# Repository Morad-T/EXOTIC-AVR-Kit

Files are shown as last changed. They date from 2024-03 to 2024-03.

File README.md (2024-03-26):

# AVR Kit

AVR Dev. Kit based on the ATMEGA32A
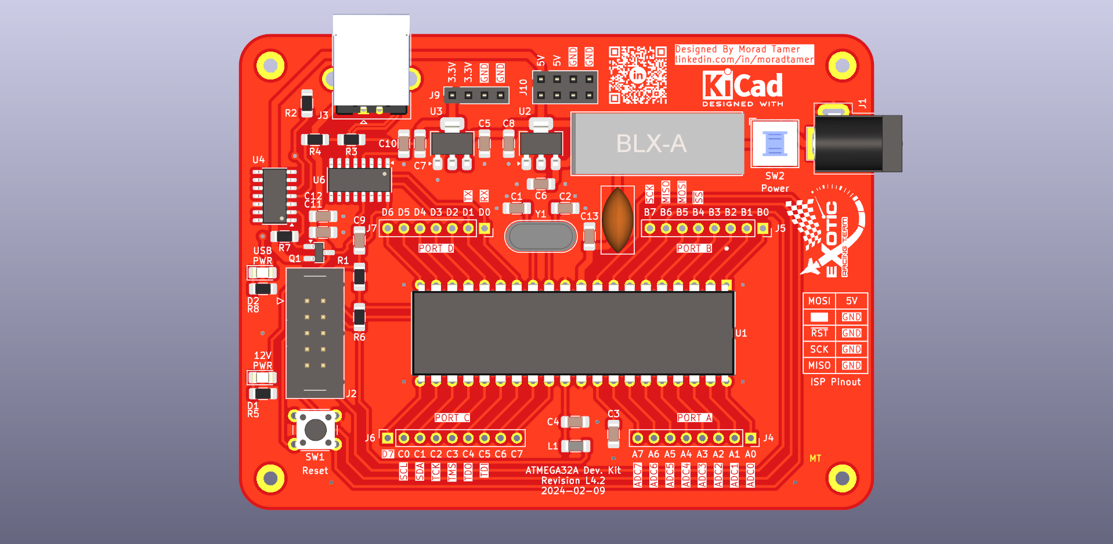
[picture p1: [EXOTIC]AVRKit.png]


## Features

- Only 2 Layer PCB
- Can accomodate ZIF or normal 40-Pin sockets
- Over Current Protection
- CH340C USB to UART Interface
- Direct 10-Pin ISP Interface

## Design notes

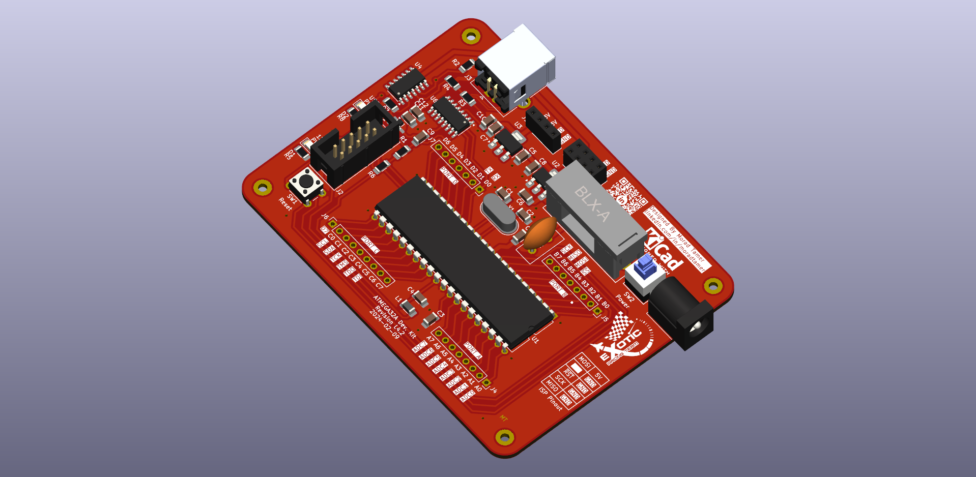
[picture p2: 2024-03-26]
[EXOTIC]AVRKitIsometric.png

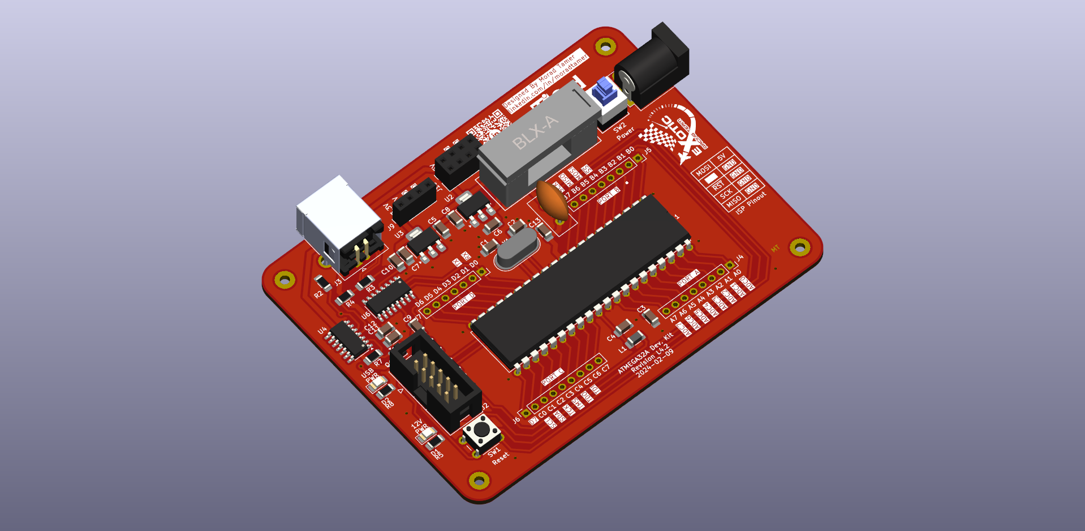
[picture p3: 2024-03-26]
[EXOTIC]AVRKitIsometric2.png

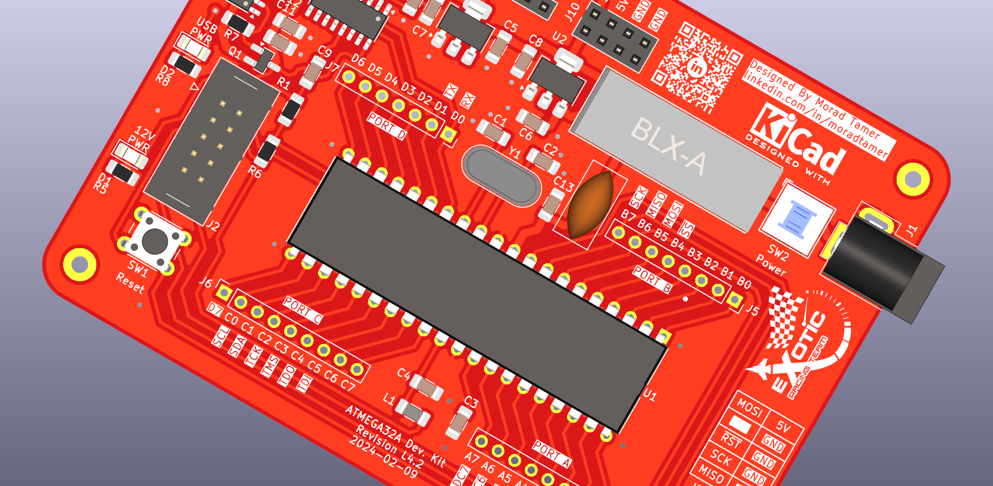
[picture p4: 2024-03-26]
[EXOTIC]AVRKitCover.png

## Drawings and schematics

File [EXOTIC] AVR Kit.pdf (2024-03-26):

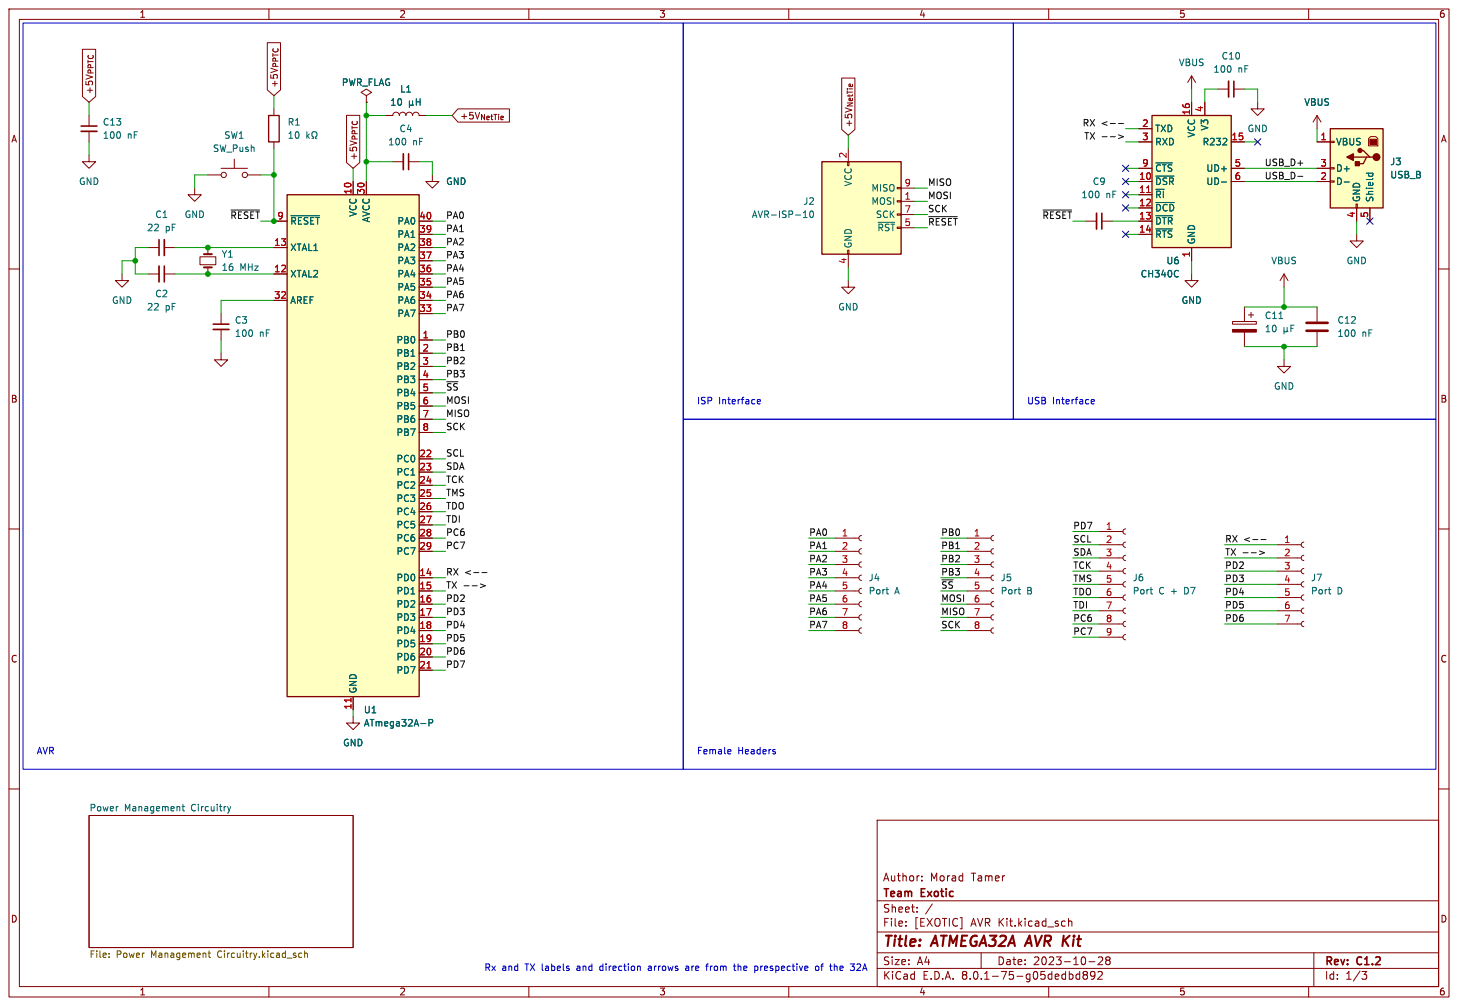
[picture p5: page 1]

VBUS GND +5V_{NetTie} +5V_{PPTC} +5V_{PPTC}

4 UD+ 5 UD- 6 ~{CTS} 9 U6 CH340C GND

1 ~{DSR} 10 ~{RI} 11 ~{DCD} 12 ~{DTR} 13 ~{RTS} 14 R232 VCC 15 16 TXD 2 RXD 3 V3

4 UD+ 5 UD- 6 ~{CTS} 9 GND

SCL PD5 PD3 PD6 PD2 TX --> MOSI MISO

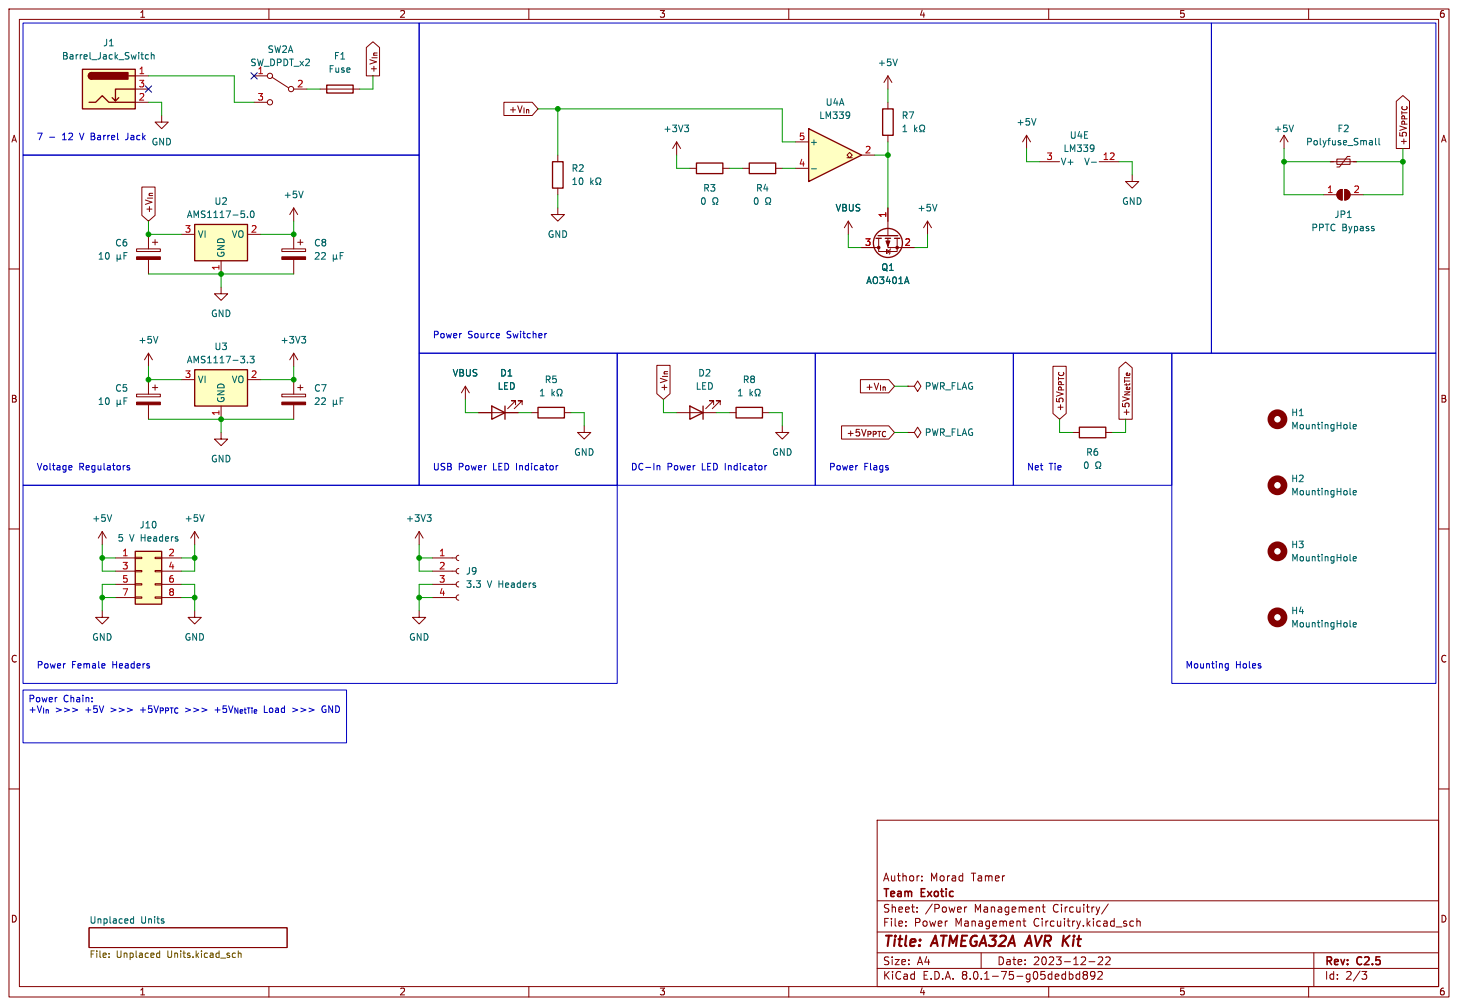
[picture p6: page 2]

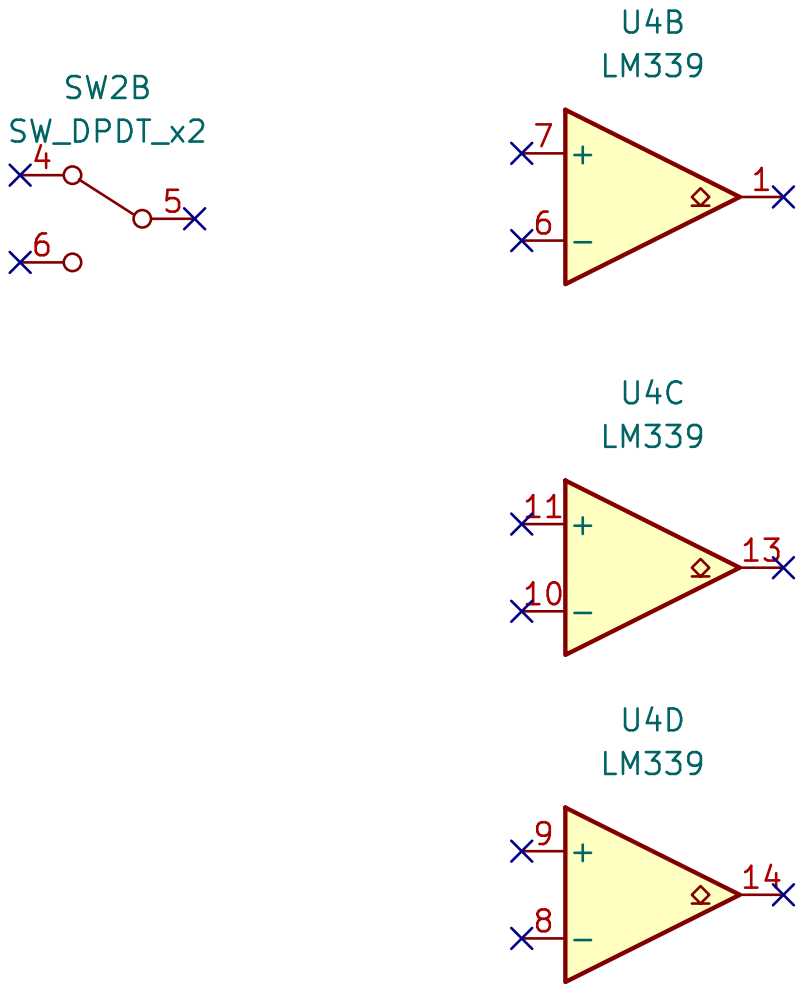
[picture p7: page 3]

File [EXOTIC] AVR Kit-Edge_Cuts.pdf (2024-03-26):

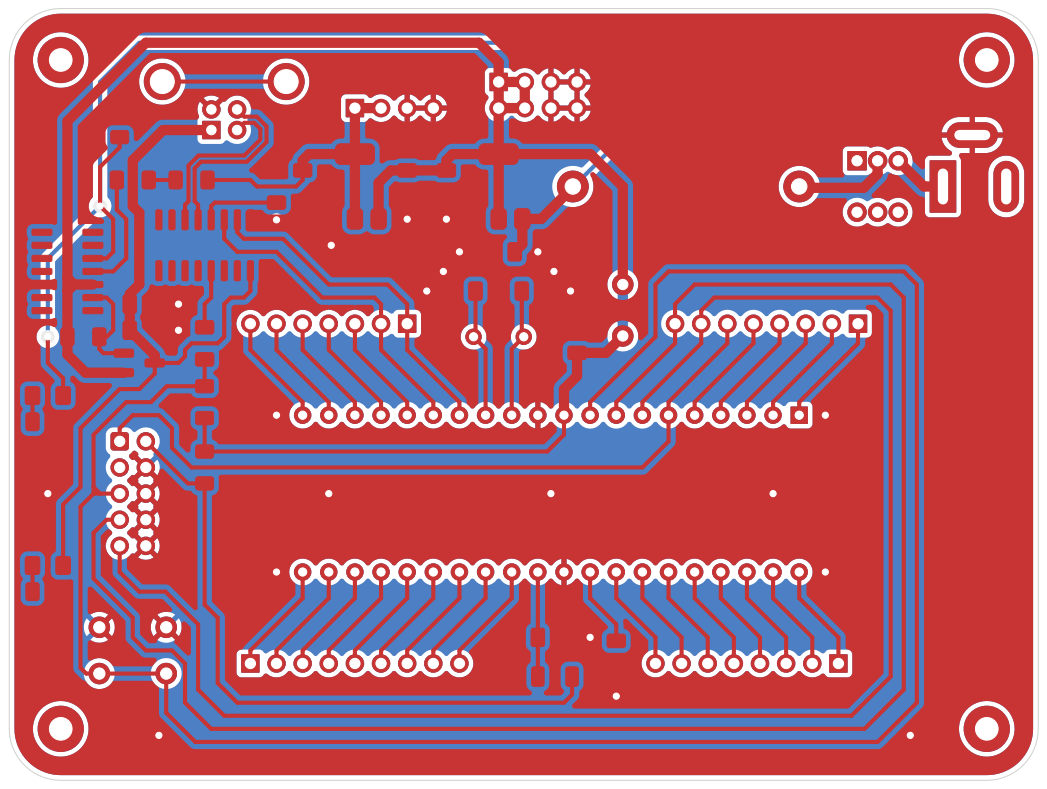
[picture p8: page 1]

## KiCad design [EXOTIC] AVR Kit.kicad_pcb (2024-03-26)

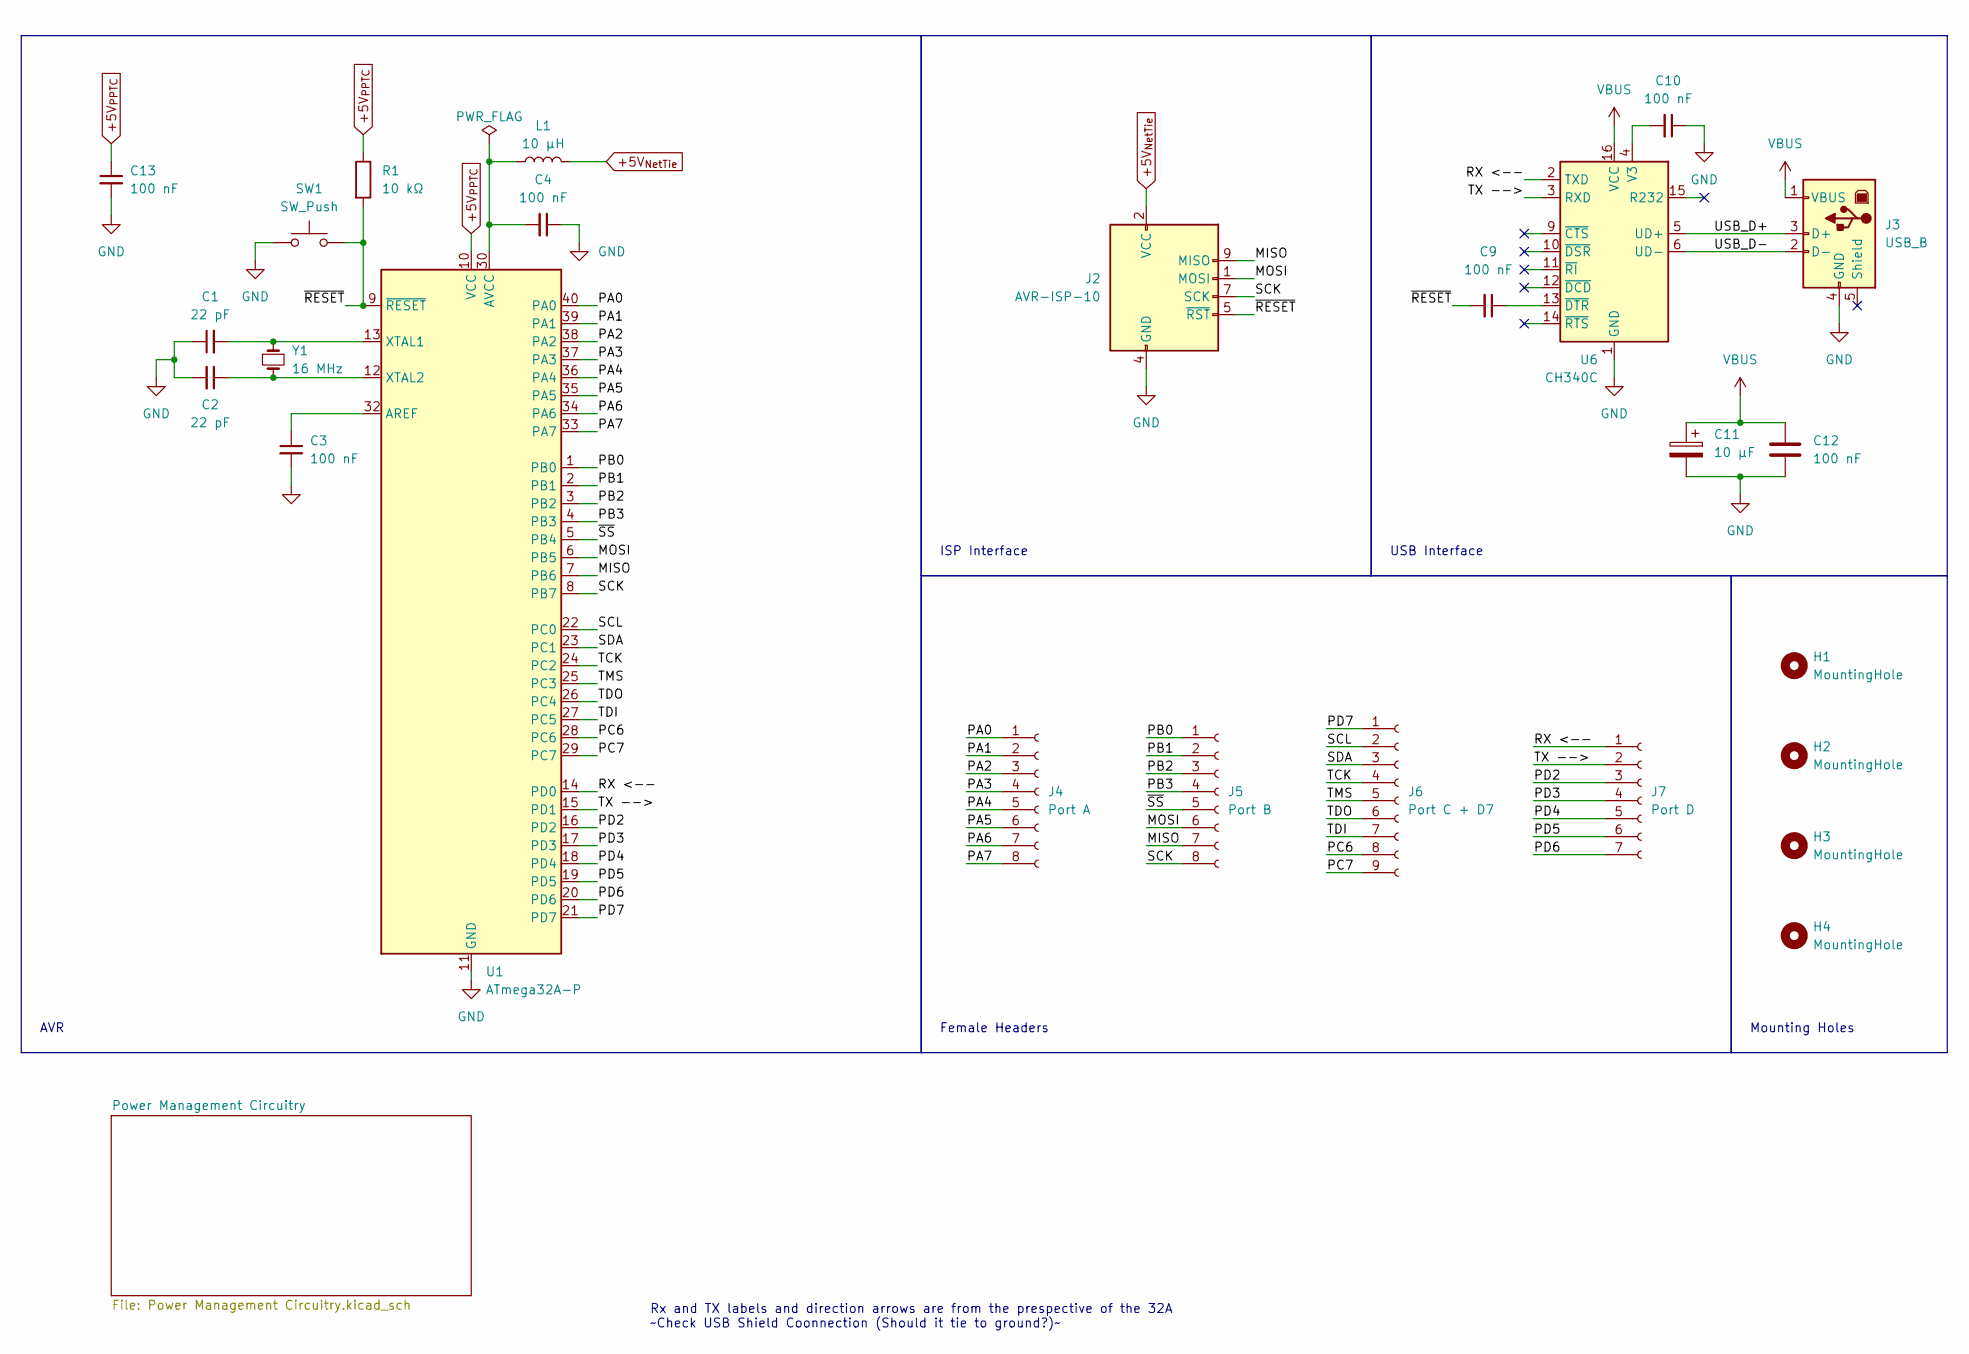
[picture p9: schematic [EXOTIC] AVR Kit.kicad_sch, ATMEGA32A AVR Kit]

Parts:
C1, C2: 22 pF; C_1206_3216Metric_Pad1.33x1.80mm_HandSolder
C3, C4, C9, C10, C12, C13: 100 nF; C_1206_3216Metric_Pad1.33x1.80mm_HandSolder
C11: 10 µF; C_1206_3216Metric_Pad1.33x1.80mm_HandSolder
H1, H2, H3, H4: MountingHole; MountingHole_2.2mm_M2_Pad
J2: AVR-ISP-10; IDC-Header_2x05_P2.54mm_Vertical
J3: USB_B; USB_B_Connector_Horizontal
J4: Port A; PinSocket_1x08_P2.54mm_Vertical
J5: Port B; PinSocket_1x08_P2.54mm_Vertical
J6: Port C + D7; PinSocket_1x09_P2.54mm_Vertical
J7: Port D; PinSocket_1x07_P2.54mm_Vertical
L1: 10 µH; L_1206_3216Metric_Pad1.22x1.90mm_HandSolder
R1: 10 kΩ; R_1206_3216Metric_Pad1.30x1.75mm_HandSolder
SW1: SW_Push; SW_PUSH_6mm_H4.3mm
U1: ATmega32A-P; ZIF_Socket_40_Circular_Pads
U6: CH340C; SOIC-16_3.9x9.9mm_P1.27mm
Y1: 16 MHz; Crystal_HC49-4H_Vertical_Centered

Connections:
+5V_{NetTie}: J2.2 (VCC), L1.2; also elsewhere on the board
+5V_{PPTC}: C13.1, R1.1, U1.10 (VCC); also elsewhere on the board
/MISO: J2.9 (MISO), J5.7, U1.7 (PB6)
/MOSI: J2.1 (MOSI), J5.6, U1.6 (PB5)
/PA0: J4.1, U1.40 (PA0)
/PA1: J4.2, U1.39 (PA1)
/PA2: J4.3, U1.38 (PA2)
/PA3: J4.4, U1.37 (PA3)
/PA4: J4.5, U1.36 (PA4)
/PA5: J4.6, U1.35 (PA5)
/PA6: J4.7, U1.34 (PA6)
/PA7: J4.8, U1.33 (PA7)
/PB0: J5.1, U1.1 (PB0)
/PB1: J5.2, U1.2 (PB1)
/PB2: J5.3, U1.3 (PB2)
/PB3: J5.4, U1.4 (PB3)
/PC6: J6.8, U1.28 (PC6)
/PC7: J6.9, U1.29 (PC7)
/PD2: J7.3, U1.16 (PD2)
/PD3: J7.4, U1.17 (PD3)
/PD4: J7.5, U1.18 (PD4)
/PD5: J7.6, U1.19 (PD5)
/PD6: J7.7, U1.20 (PD6)
/PD7: J6.1, U1.21 (PD7)
/RX <--: J7.1, U1.14 (PD0), U6.2 (TXD)
/SCK: J2.7 (SCK), J5.8, U1.8 (PB7)
/SCL: J6.2, U1.22 (PC0)
/SDA: J6.3, U1.23 (PC1)
/TCK: J6.4, U1.24 (PC2)
/TDI: J6.7, U1.27 (PC5)
/TDO: J6.6, U1.26 (PC4)
/TMS: J6.5, U1.25 (PC3)
/TX -->: J7.2, U1.15 (PD1), U6.3 (RXD)
/USB_D+: J3.3 (D+), U6.5 (UD+)
/USB_D-: J3.2 (D-), U6.6 (UD-)
/~RESET: C9.2, J2.5 (~RST), R1.2, SW1.1, U1.9 (~RESET)
/~SS: J5.5, U1.5 (PB4)
GND: C1.1, C2.2, C3.2, C4.1, C10.1, C11.2, C12.1, C13.2, J2.4 (GND), J2.6 (GND), J2.8 (GND), J2.10 (GND), J3.4 (GND), SW1.2, U1.11 (GND), U1.31 (GND), U6.1 (GND); also elsewhere on the board
unnamed: C3.1, U1.32 (AREF)
unnamed: C4.2, L1.1, U1.30 (AVCC)
unnamed: C1.2, U1.13 (XTAL1), Y1.1
unnamed: C2.1, U1.12 (XTAL2), Y1.2
unnamed: C10.2, U6.4 (V3)
unnamed: C9.1, U6.13 (~DTR)
VBUS: C11.1, C12.2, J3.1 (VBUS), U6.16 (VCC); also elsewhere on the board

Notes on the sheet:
Female Headers
AVR
Mounting Holes
ISP Interface
Rx and TX labels and direction arrows are from the prespective of the 32A ~Check USB Shield Coonnection (Should it tie to ground?)~
USB Interface

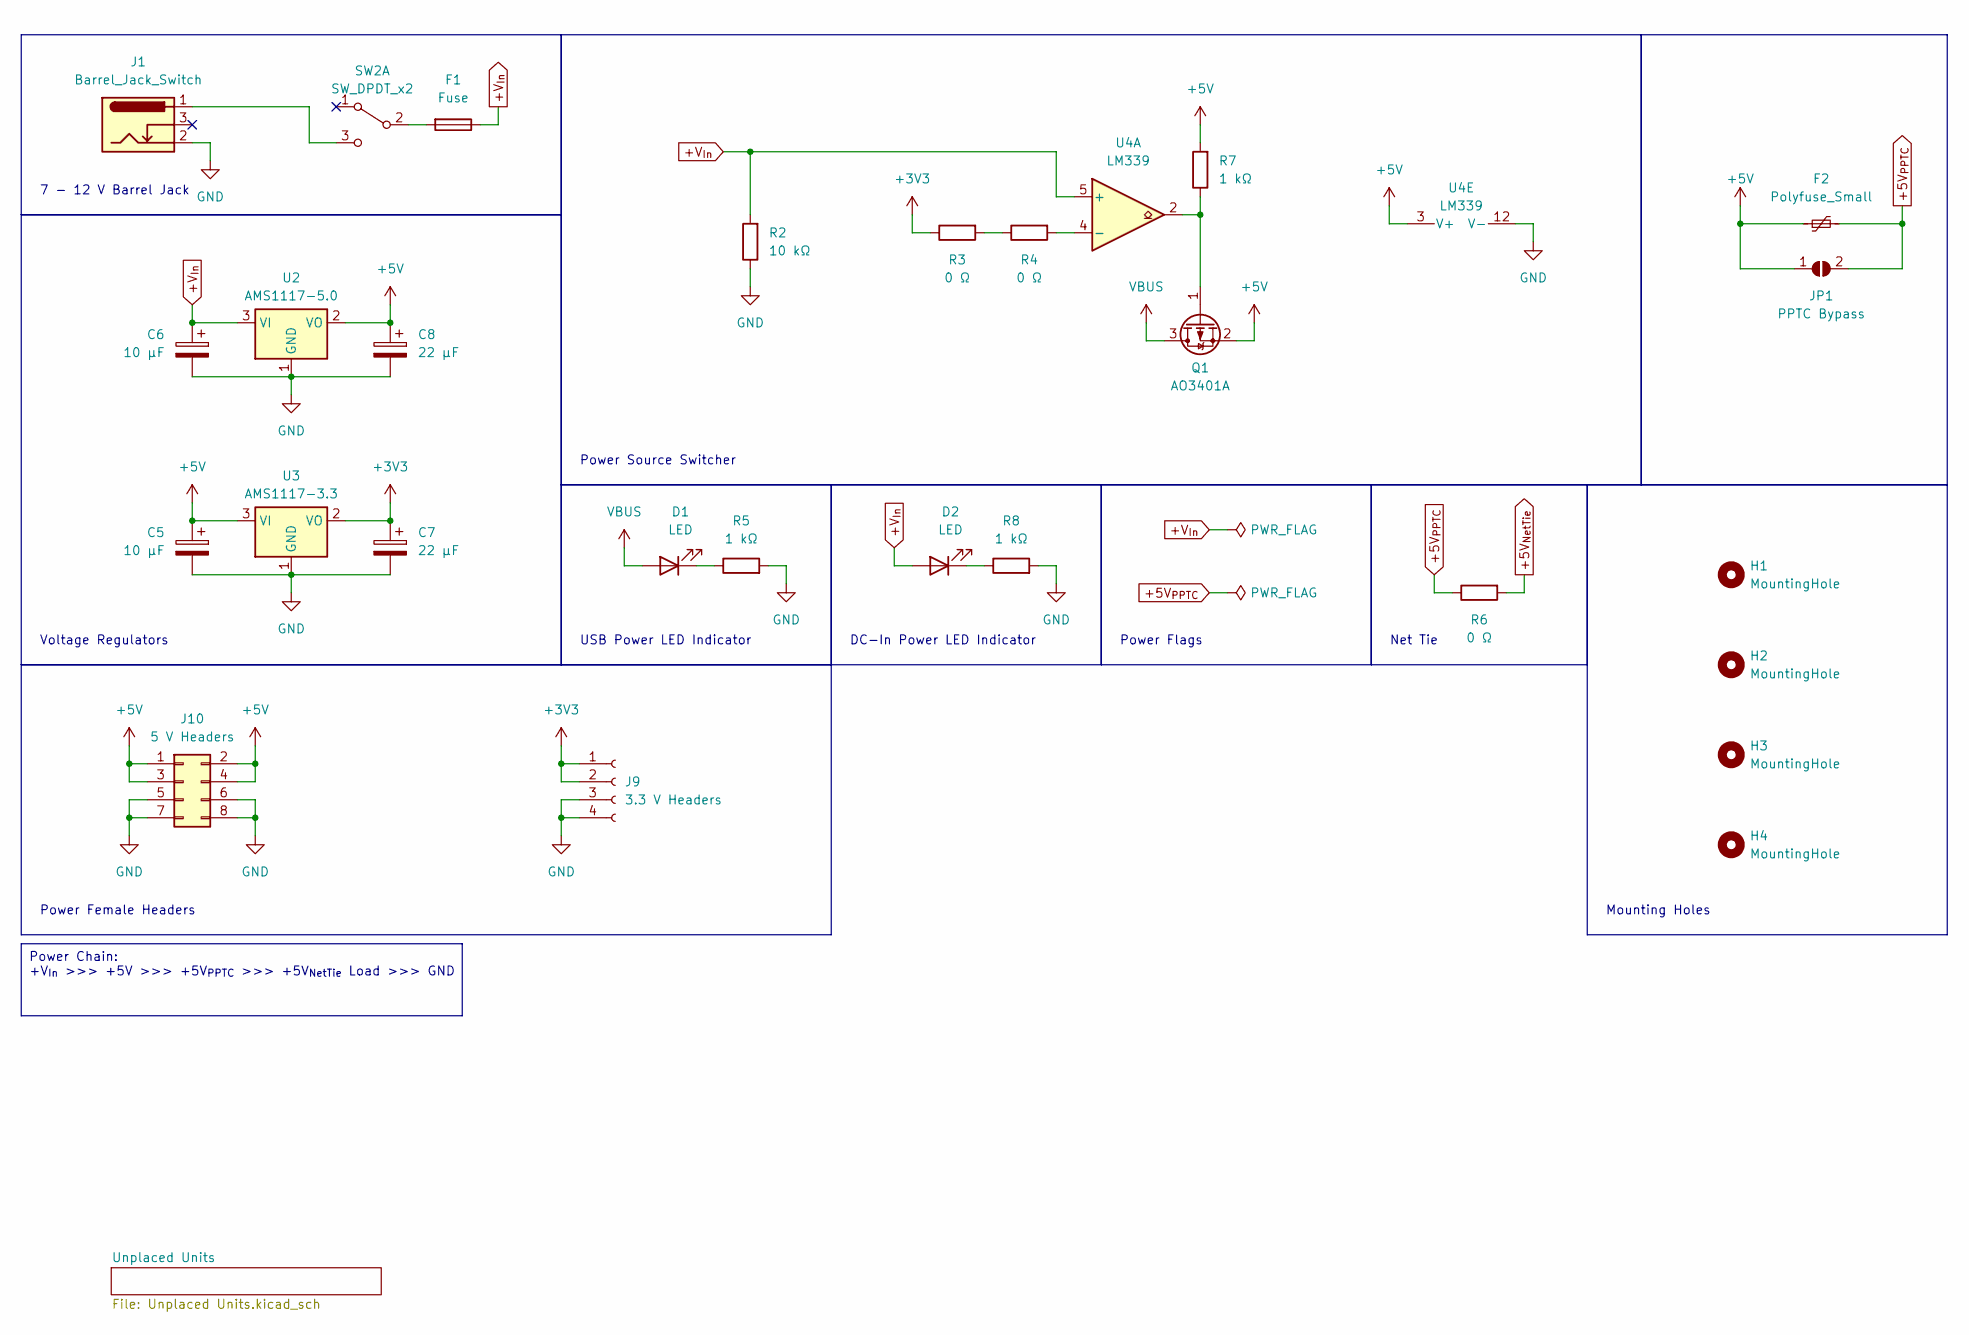
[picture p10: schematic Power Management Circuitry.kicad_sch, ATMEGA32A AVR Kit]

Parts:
C5, C6: 10 µF; C_1206_3216Metric_Pad1.33x1.80mm_HandSolder
C7, C8: 22 µF; C_1206_3216Metric_Pad1.33x1.80mm_HandSolder
D1, D2: LED; LED_1206_3216Metric_Pad1.42x1.75mm_HandSolder
F1: Fuse; Fuseholder_with_Cover_5x20mm_Horizontal
F2: Polyfuse_Small; C_Disc_D10.5mm_W5.0mm_P5.00mm
H1, H2, H3, H4: MountingHole; MountingHole_2.2mm_M2_Pad
J1: Barrel_Jack_Switch; BarrelJack_Horizontal
J9: 3.3 V Headers; PinSocket_1x04_P2.54mm_Vertical
J10: 5 V Headers; PinSocket_2x04_P2.54mm_Vertical
JP1: PPTC Bypass; SolderJumper-2_P1.3mm_Open_RoundedPad1.0x1.5mm
Q1: AO3401A; SOT-23_Handsoldering
R2: 10 kΩ; R_1206_3216Metric_Pad1.30x1.75mm_HandSolder
R3, R4, R6: 0 Ω; R_1206_3216Metric_Pad1.30x1.75mm_HandSolder
R5, R7, R8: 1 kΩ; R_1206_3216Metric_Pad1.30x1.75mm_HandSolder
SW2: SW_DPDT_x2; SW_Push_DPDT_Toggle_7.0mm
U2: AMS1117-5.0; SOT-223-3_TabPin2
U3: AMS1117-3.3; SOT-223-3_TabPin2
U4: LM339; SOIC-14_3.9x8.7mm_P1.27mm

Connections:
+3V3: C7.1, J9.1, J9.2, R3.1, U3.2 (VO)
+5V: C5.1, C8.1, F2.1, J10.1, J10.2, J10.3, J10.4, JP1.1 (A), Q1.2 (S), R7.2, U2.2 (VO), U3.3 (VI), U4.3 (V+)
+5V_{NetTie}: R6.2; also elsewhere on the board
+5V_{PPTC}: F2.2, JP1.2 (B), R6.1; also elsewhere on the board
+V_{In}: C6.1, D2.2 (A), F1.1, R2.2, U2.3 (VI), U4.5 (+)
GND: C5.2, C6.2, C7.2, C8.2, J1.2, J9.3, J9.4, J10.5, J10.6, J10.7, J10.8, R2.1, R5.2, R8.2, U2.1 (GND), U3.1 (GND), U4.12 (V-); also elsewhere on the board
unnamed: D1.1 (K), R5.1
unnamed: D2.1 (K), R8.1
unnamed: Q1.1 (G), R7.1, U4.2
unnamed: R3.2, R4.1
unnamed: F1.2, SW2.2 (B)
unnamed: J1.1, SW2.3 (C)
unnamed: R4.2, U4.4 (-)
VBUS: D1.2 (A), Q1.3 (D); also elsewhere on the board

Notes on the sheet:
Power Chain: +V_{In} >>> +5V >>> +5V_{PPTC} >>> +5V_{NetTie} Load >>> GND
Mounting Holes
DC-In Power LED Indicator
Power Female Headers
7 - 12 V Barrel Jack
USB Power LED Indicator
Power Source Switcher
Net Tie
Power Flags
Voltage Regulators

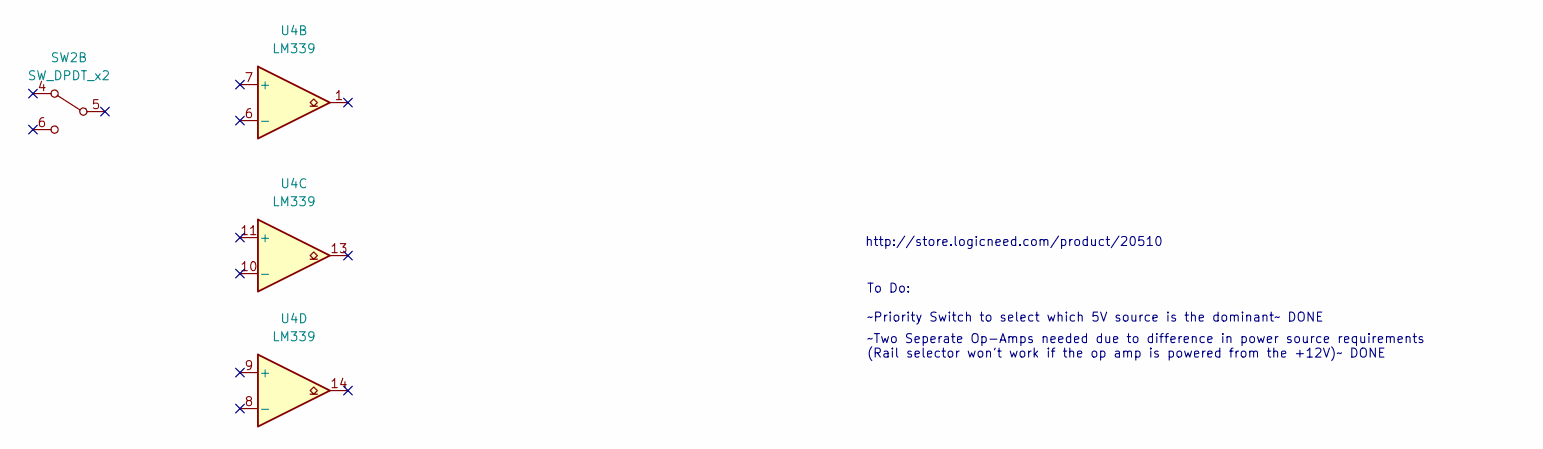
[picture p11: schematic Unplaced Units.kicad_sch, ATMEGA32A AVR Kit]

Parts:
SW2: SW_DPDT_x2; SW_Push_DPDT_Toggle_7.0mm
U4: LM339; SOIC-14_3.9x8.7mm_P1.27mm

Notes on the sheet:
http://store.logicneed.com/product/20510
~Two Seperate Op-Amps needed due to difference in power source requirements (Rail selector won't work if the op amp is powered from the +12V)~ DONE
To Do: ~Priority Switch to select which 5V source is the dominant~ DONE

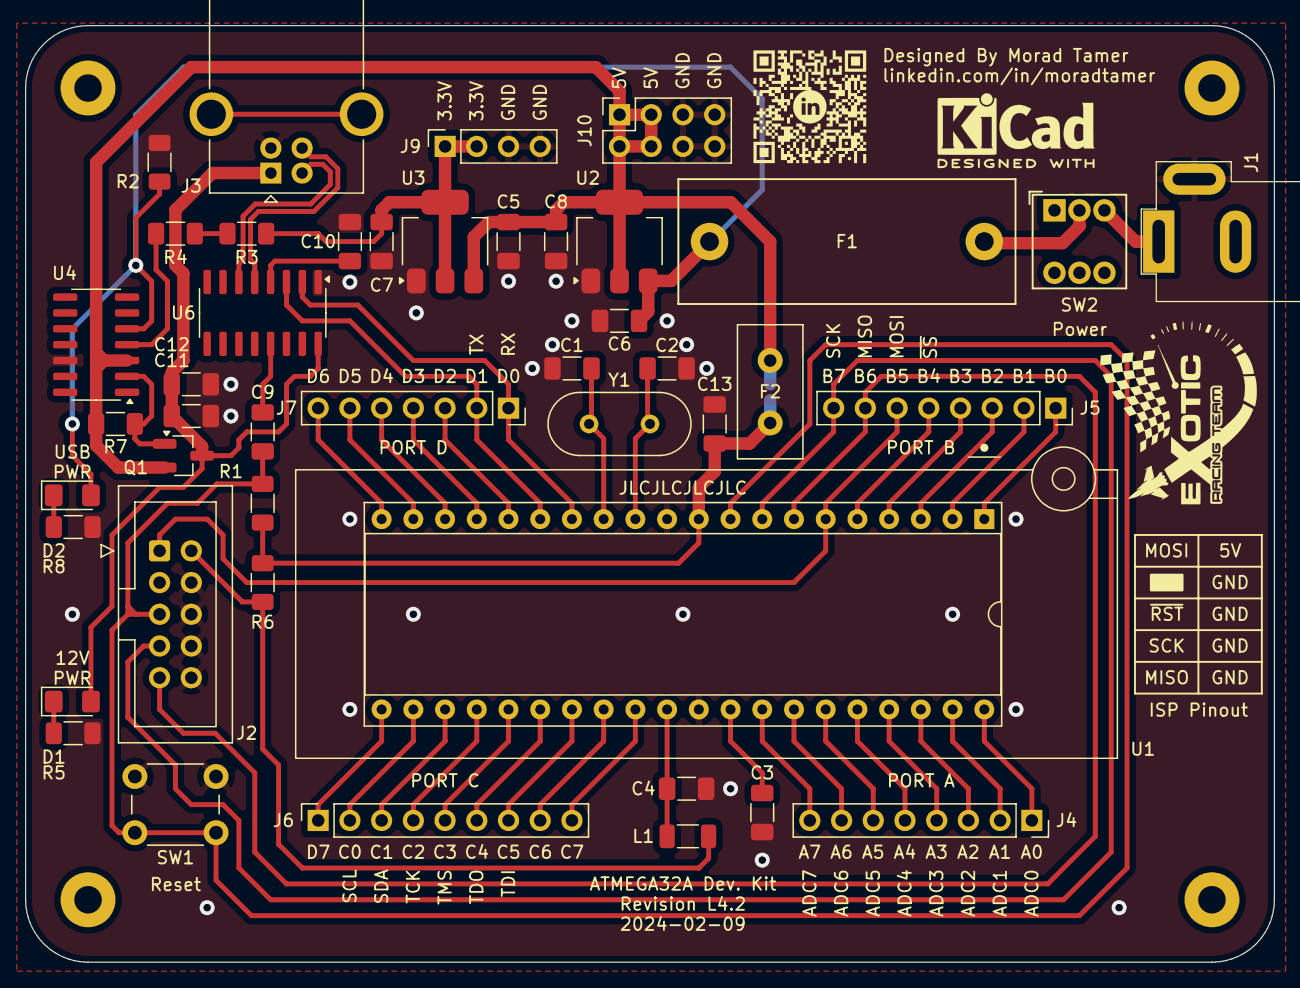
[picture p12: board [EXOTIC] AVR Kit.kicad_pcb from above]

Board: 2 copper layers, 100.0 x 75.0 mm, 49 parts (1 on the bottom side), 55 nets.

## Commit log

2023-12-14 Update Power Management Circuitry.kicad_sch
    [Power Management Circuitry.kicad_sch]
2023-12-14 Schematic Revision C2
    [Power Management Circuitry.kicad_sch, Unplaced Units.kicad_sch, [EXOTIC] AVR Kit.kicad_sch]
2023-12-14 Finished recreating the schematic
    Created new footprints for DC Barrel Jack and Fuse Holder (3d models still require adjustment and finalize shunt resistance value and footprint)
    [Power Management Circuitry.kicad_sch, Unplaced Units.kicad_sch]
2023-12-14 Most work done
    [Power Management Circuitry.kicad_sch, Shunt Resistor Array.kicad_sch, [EXOTIC] AVR Kit.kicad_pcb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]
2023-12-14 Added The 3D Models
    [[EXOTIC] AVR Kit.kicad_pcb]
2023-12-14 Images Exported From 3D View
    [[EXOTIC] AVR Kit.kicad_pcb]
2023-12-14 done something
    [Power Management Circuitry.kicad_sch, Unplaced Units.kicad_sch, [EXOTIC] AVR Kit.kicad_sch]
2023-12-14 Clean Up
    [BOM.xlsx, [EXOTIC] AVR Kit (No Headers).kicad_pcb, [EXOTIC] AVR Kit WIP.kicad_pcb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]
2023-12-14 Schematic Touch Up
    [[EXOTIC] AVR Kit.kicad_sch]
2023-12-14 PCB Touch Up
    [[EXOTIC] AVR Kit.kicad_pcb]
2023-12-14 Rev 2.1
    [[EXOTIC] AVR Kit.kicad_pcb]
2023-12-14 Update [EXOTIC] AVR Kit.kicad_sch
    [[EXOTIC] AVR Kit.kicad_sch]
2023-12-14 Update [EXOTIC] AVR Kit.kicad_pcb
    [[EXOTIC] AVR Kit.kicad_pcb]
2023-12-17 Update README.md
    Removed parenthesis to double check circuit operation
2023-12-20 Rev. 3
    [[EXOTIC] AVR Kit.kicad_pcb, [EXOTIC] AVR Kit.kicad_sch]
2023-12-20 Rev 3.1
    [Power Management Circuitry.kicad_sch, Unplaced Units.kicad_sch, [EXOTIC] AVR Kit.kicad_pcb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]
2023-12-20 Some Tweaks
    [[EXOTIC] AVR Kit.kicad_pcb]
2023-12-22 Rev 3.2
    Cleaned Up Schematic
    Revised Layout
    [Power Management Circuitry.kicad_sch, [EXOTIC] AVR Kit.kicad_pcb, [EXOTIC] AVR Kit.kicad_sch]
2023-12-22 Added 5V and 3.3V O/P Pins
    [[EXOTIC] AVR Kit.kicad_pcb]
2023-12-22 Schematic Organization
    [Power Management Circuitry.kicad_sch, [EXOTIC] AVR Kit.kicad_sch]
2023-12-22 Added My Initials
    [[EXOTIC] AVR Kit.kicad_pcb]
2024-01-05 Added I2C Labels
    [Power Management Circuitry.kicad_sch, [EXOTIC] AVR Kit.kicad_pcb, [EXOTIC] AVR Kit.kicad_sch]
2024-01-05 Rounded Corners
    [[EXOTIC] AVR Kit.kicad_pcb]
2024-01-05 Some Touch Ups
    [[EXOTIC] AVR Kit.kicad_pcb]
2024-01-05 Improved Schematics' Readability
    [Power Management Circuitry.kicad_sch, [EXOTIC] AVR Kit.kicad_pcb, [EXOTIC] AVR Kit.kicad_sch]
2024-01-06 More Touch Ups
    Tidied the schematic
    Added Dimensions of the PCB on User.Drawings Layer
    [Power Management Circuitry.kicad_sch, [EXOTIC] AVR Kit.kicad_pcb, [EXOTIC] AVR Kit.kicad_sch]
2024-01-14 New Subrevision
    [Power Management Circuitry.kicad_sch, [EXOTIC] AVR Kit D7 Placed Beside Rest D.kicad_pcb, [EXOTIC] AVR Kit Flipped Port C.kicad_pcb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]
2024-01-14 Minor Tweak
    [[EXOTIC] AVR Kit.kicad_pcb]
2024-01-24 More Tweaks
    [[EXOTIC] AVR Kit.kicad_pcb]
2024-02-04 Pre Rev. 4
    [Power Management Circuitry Original.kicad_sch, Unplaced Units.kicad_sch, [EXOTIC] AVR Kit D7 Placed Beside Rest D.kicad_pcb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]
2024-03-07 Rev 3.99
    [Power Management Circuitry.kicad_sch, Unplaced Units.kicad_sch, [EXOTIC] AVR Kit.csv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]
2024-03-07 Rev. L4.2
    [Power Management Circuitry.kicad_sch, Unplaced Units.kicad_sch, [EXOTIC] AVR Kit.kicad_pcb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]
2024-03-26 Auto-Reset Circuit Simulation
